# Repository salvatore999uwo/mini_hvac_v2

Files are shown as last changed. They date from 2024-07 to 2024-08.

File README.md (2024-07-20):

# mini_hvac_v2
Second version of the temperature control system for a small model room.

Photos:
As shown below, this version is made from three parts: Wooden structure, electronic boards, and thermal transfer area. 
The wooden structure is made up of a plywood base and a model room built from studs. There will be a drywall covering over the stud room to simulate a real temperature-controlled room.
The electronic boards are simply the PCB and the power supply for the project. There will be several wires running between the boards and the thermal transfer area.
The thermal transfer area is shown by the heatsinks and fans on the picture below. This area is composed of the TEC module, which creates a large temperature difference, and the heatsinks and fans that allow the TEC module to move thermal energy out of or into the room.
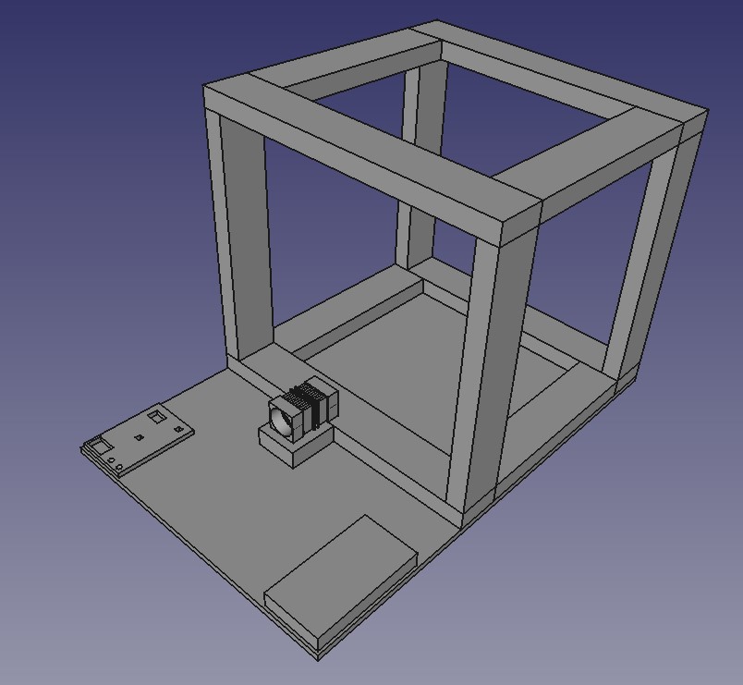
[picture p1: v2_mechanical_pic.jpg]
New Mechanical Layout


Current PCB 3D Model:
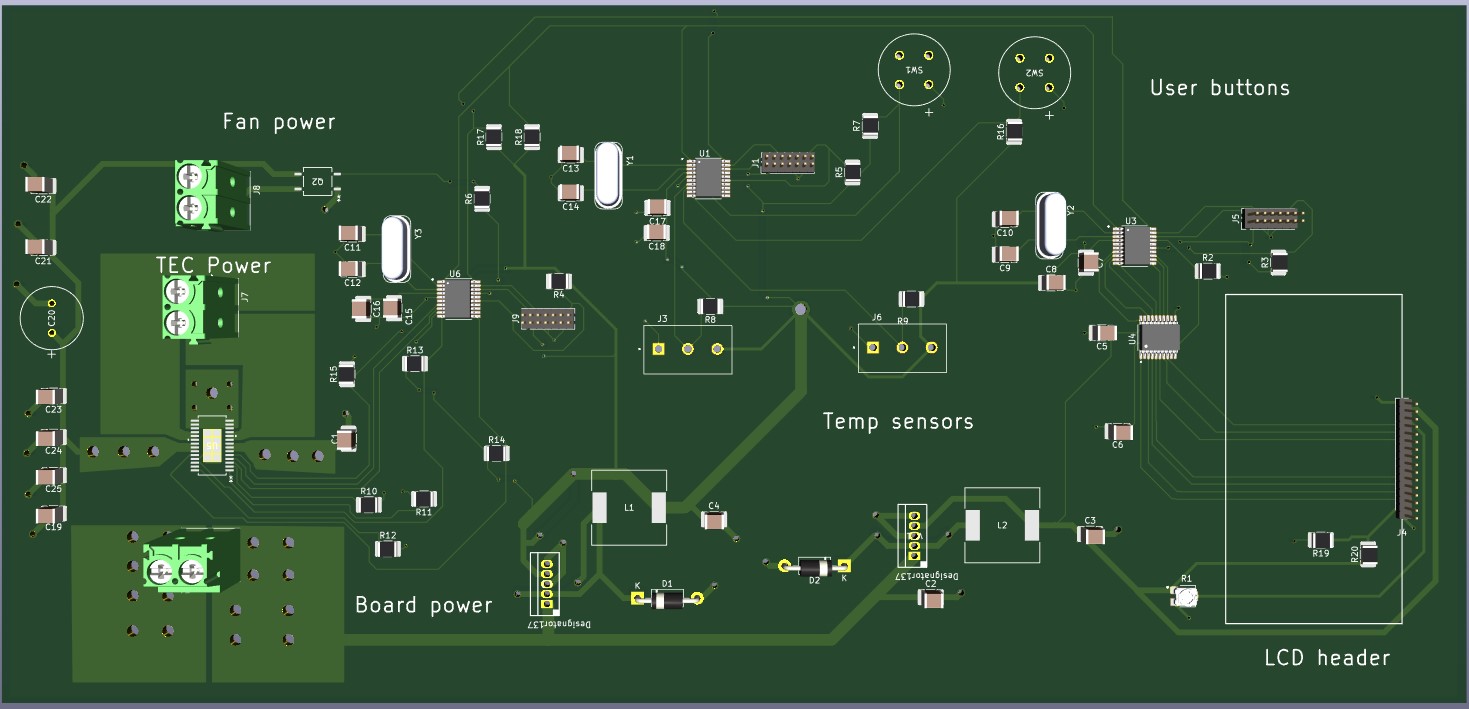
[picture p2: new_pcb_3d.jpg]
3D View


One schematic page i've been working on:
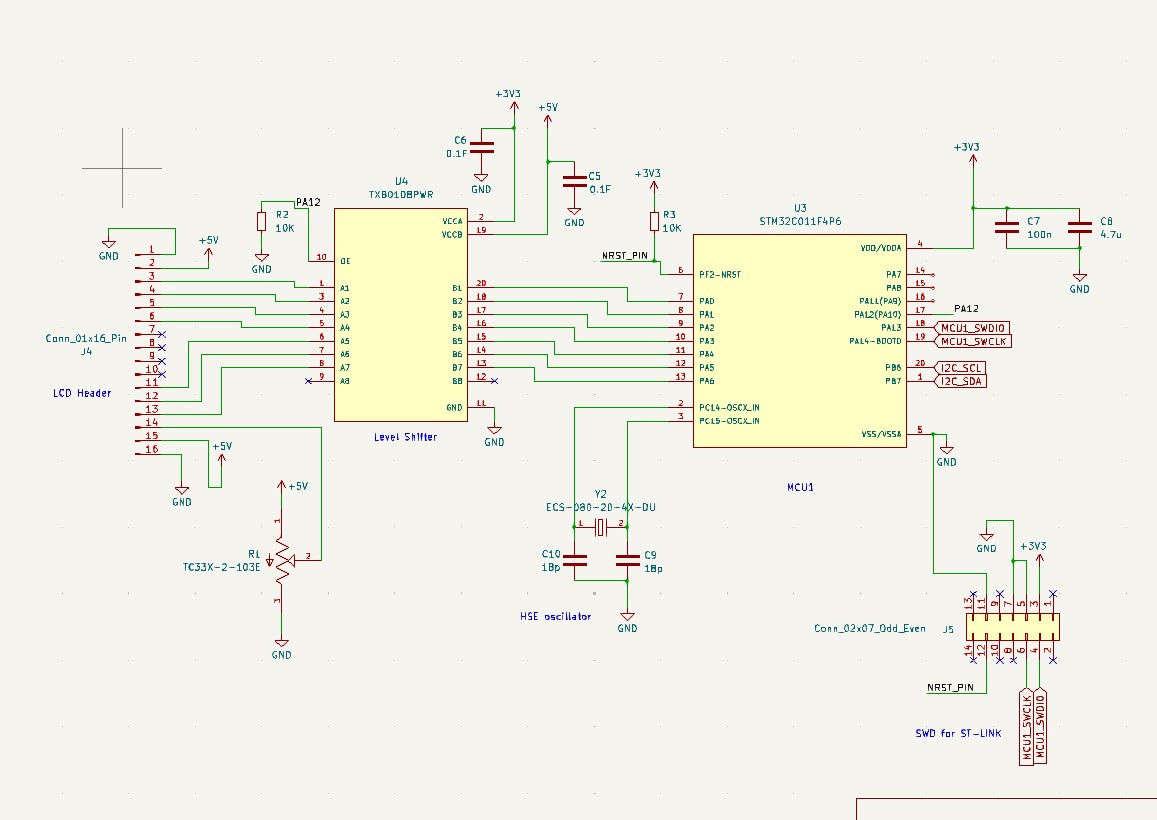
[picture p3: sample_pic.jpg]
Schematic


Current PCB Design:
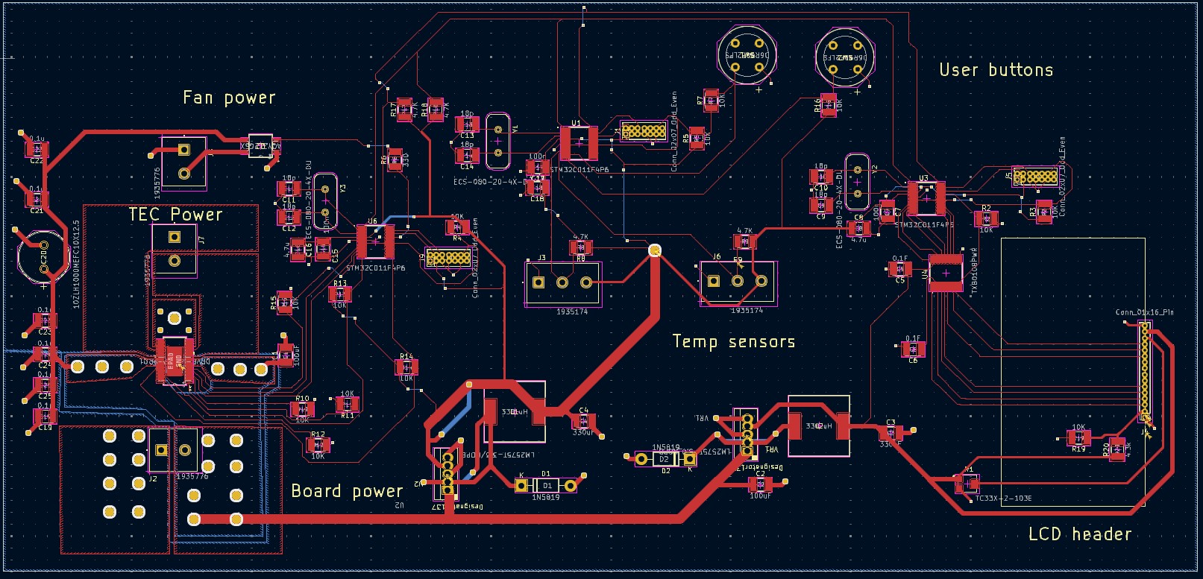
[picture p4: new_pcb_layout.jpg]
New PCB Picture


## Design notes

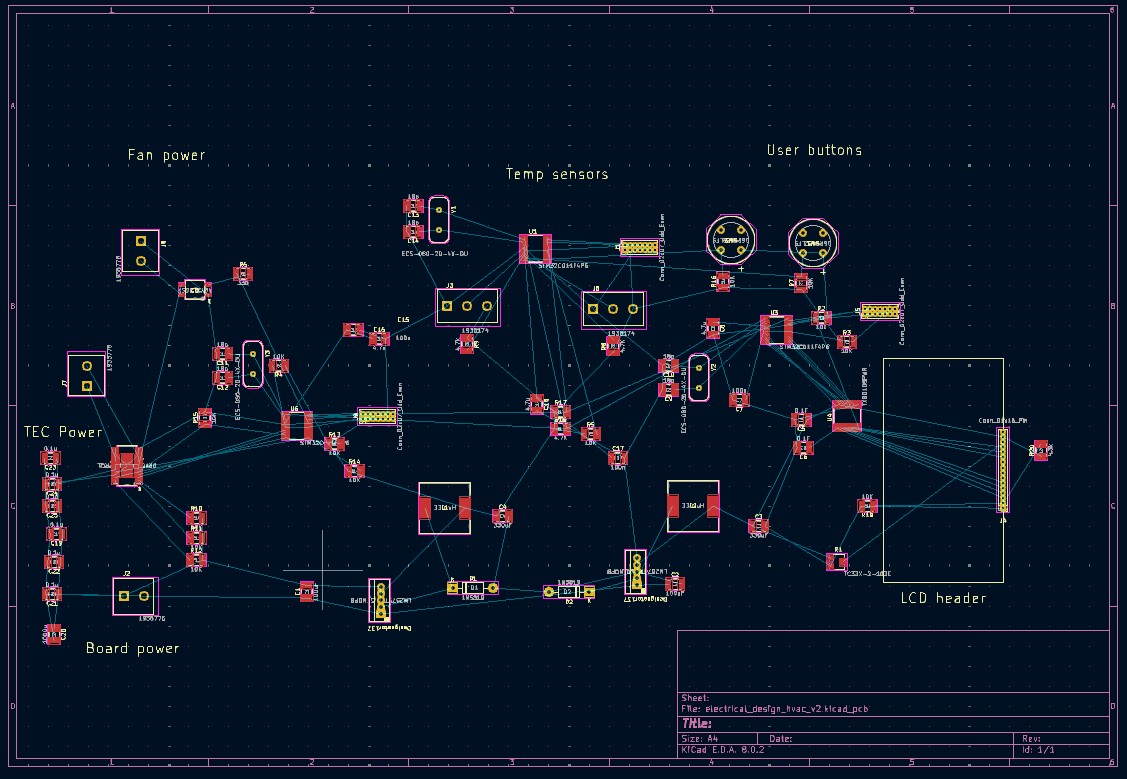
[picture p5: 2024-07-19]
pcb_one.jpg

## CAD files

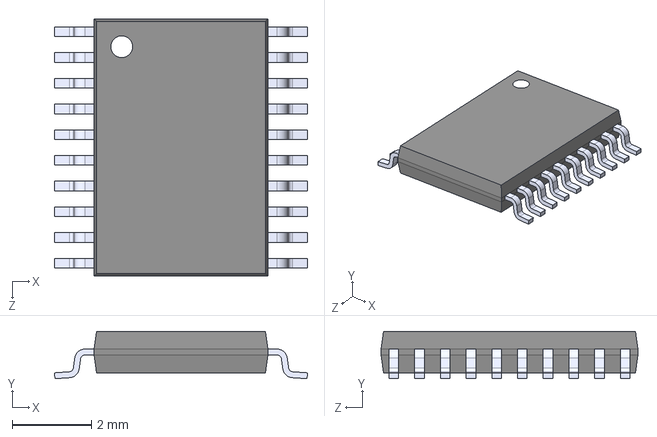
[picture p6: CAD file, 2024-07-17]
symbols_n_all/level_shifter/TXB0108PWR.step
6.40 x 1.20 x 6.50 mm

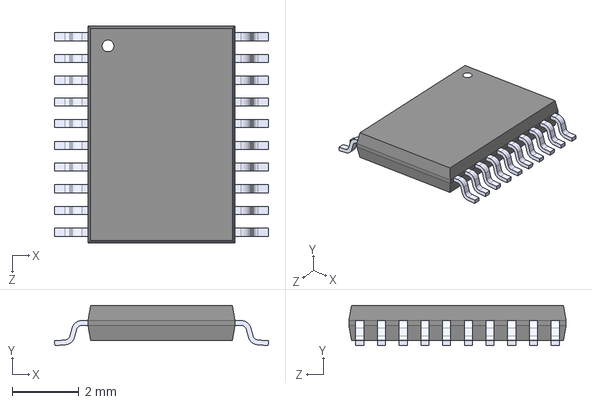
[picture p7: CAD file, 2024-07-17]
symbols_n_all/mcu/STM32C011F4P6.step
6.40 x 1.20 x 6.50 mm

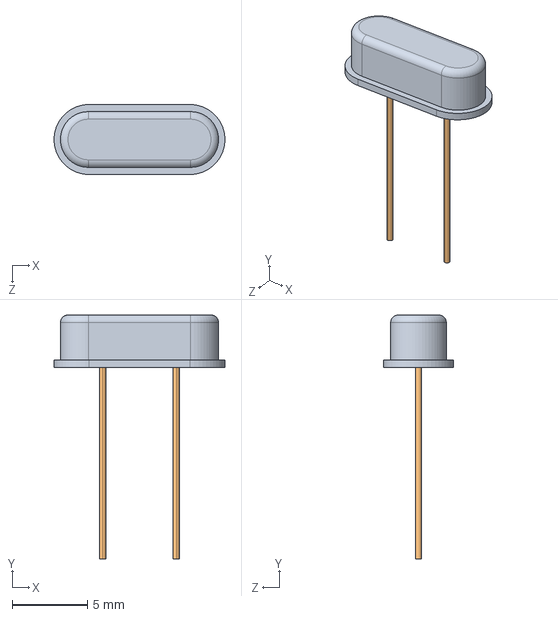
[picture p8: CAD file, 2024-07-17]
symbols_n_all/oscillator/ECS-080-20-4X-DU.step
11.4 x 16.2 x 4.65 mm

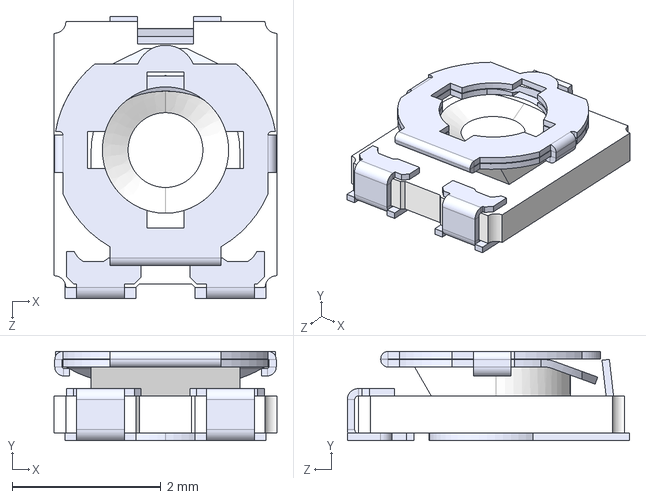
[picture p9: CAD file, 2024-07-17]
symbols_n_all/potentiometer_super/TC33X-2-103E.step
3.00 x 1.20 x 3.80 mm

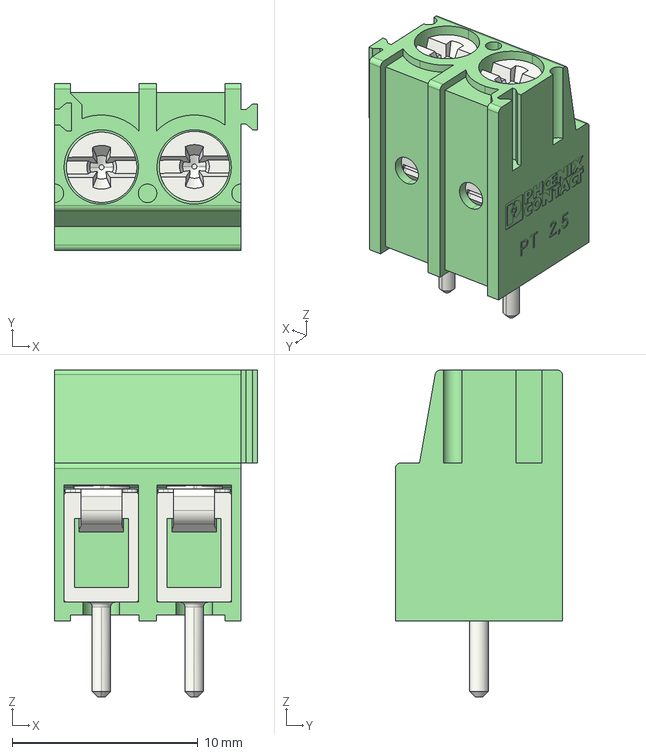
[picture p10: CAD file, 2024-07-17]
symbols_n_all/terminal_highcurrent/1935776.step
10.9 x 9.00 x 17.6 mm

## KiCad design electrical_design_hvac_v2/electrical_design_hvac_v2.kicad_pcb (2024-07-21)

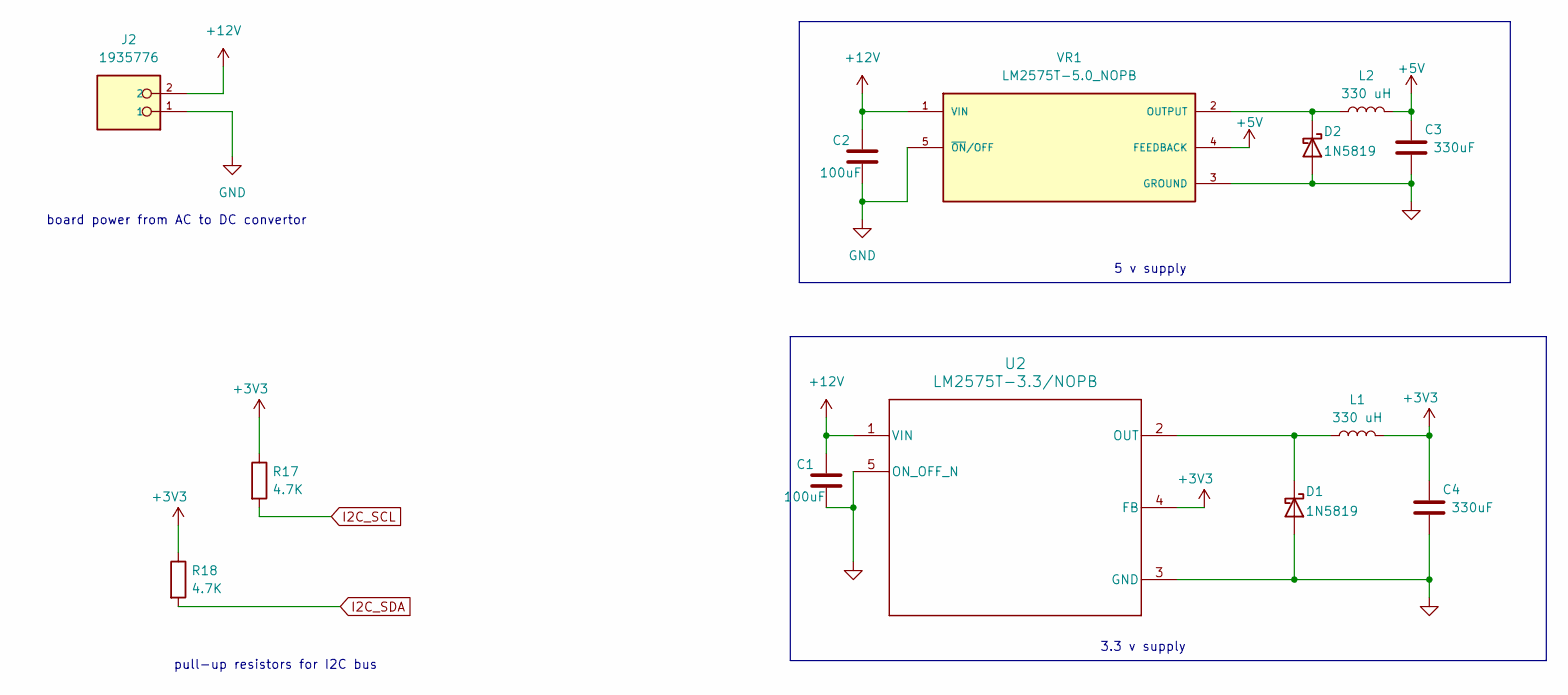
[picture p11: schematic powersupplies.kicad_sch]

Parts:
C1, C2: 100uF; C_1210_3225Metric_Pad1.33x2.70mm_HandSolder
C3, C4: 330uF; C_1210_3225Metric_Pad1.33x2.70mm_HandSolder
D1, D2: 1N5819; D_DO-41_SOD81_P10.16mm_Horizontal
J2: 1935776; PHOENIX_1935776; PARTREV 19.10.2016
L1, L2: 330 uH; IND_1210-WE-PD_WRE
R17, R18: 4.7K; R_1210_3225Metric_Pad1.30x2.65mm_HandSolder
U2: LM2575T-3.3/NOPB; KC0005A
VR1: LM2575T-5.0_NOPB; KC0005A; PARTREV E

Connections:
+5V: C3.1, L2.2, VR1.4 (FEEDBACK); also elsewhere on the board
+12V: C1.1, C2.1, J2.2, U2.1 (VIN), VR1.1 (VIN); also elsewhere on the board
GND: C1.2, C2.2, C3.2, C4.2, D1.2 (A), D2.2 (A), J2.1, U2.3 (GND), U2.5 (ON_OFF_N), VR1.3 (GROUND), VR1.5 (~ON/OFF); also elsewhere on the board
I2C_SCL: R17.2; also elsewhere on the board
I2C_SDA: R18.2; also elsewhere on the board
unnamed: D1.1 (K), L1.1, U2.2 (OUT)
unnamed: D2.1 (K), L2.1, VR1.2 (OUTPUT)

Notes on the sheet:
5 v supply
board power from AC to DC convertor
pull-up resistors for I2C bus
3.3 v supply

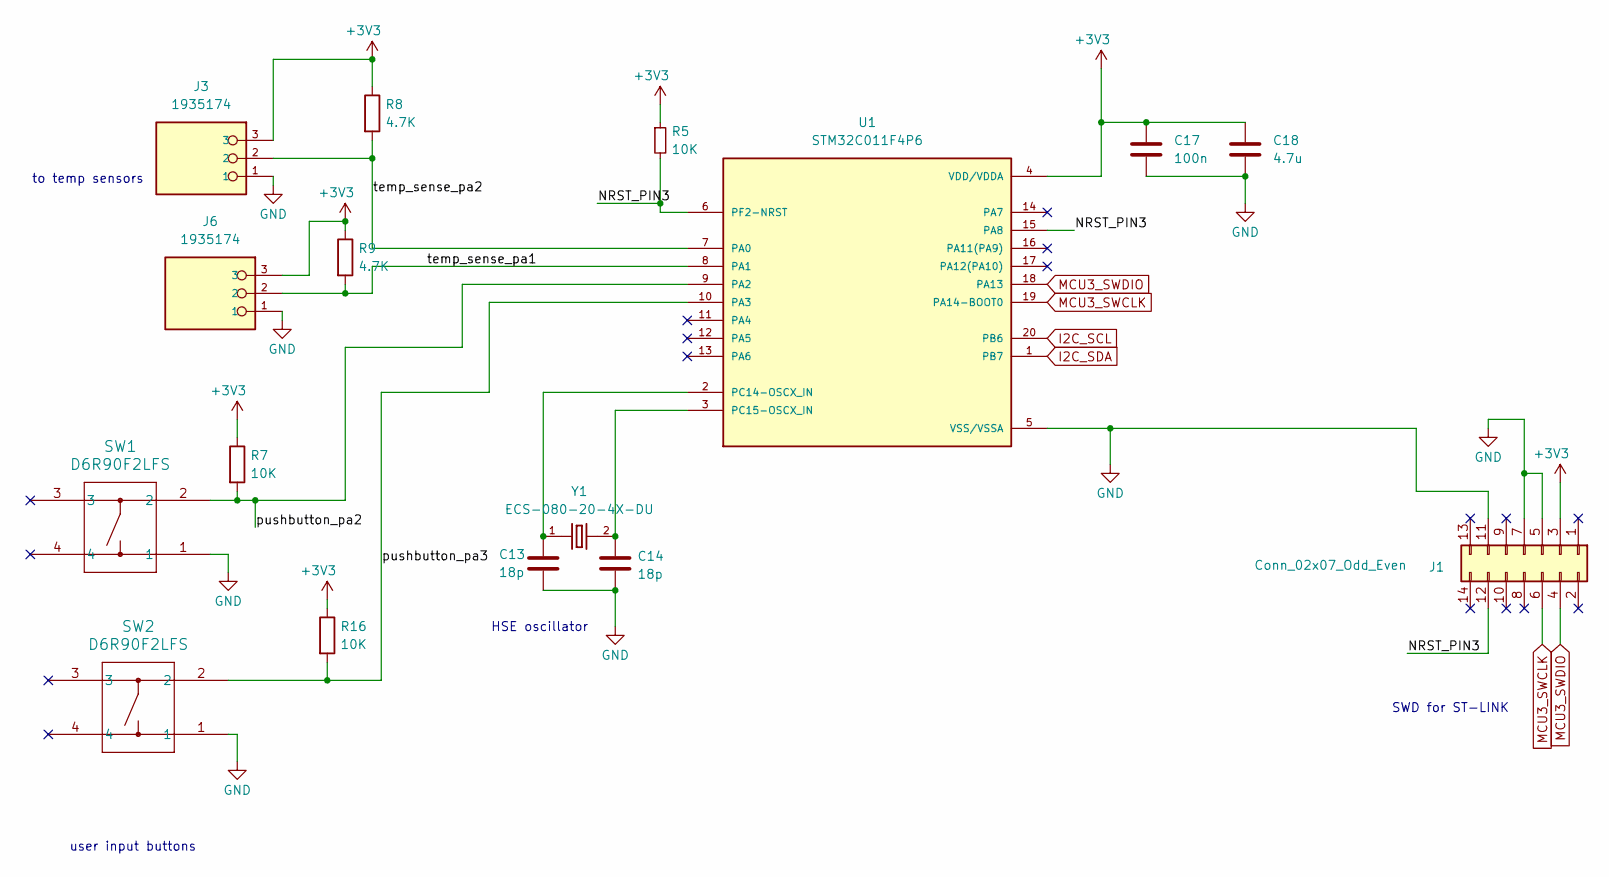
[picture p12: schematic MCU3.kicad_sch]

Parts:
C13, C14: 18p; C_1210_3225Metric_Pad1.33x2.70mm_HandSolder
C17: 100n; C_1210_3225Metric_Pad1.33x2.70mm_HandSolder
C18: 4.7u; C_1210_3225Metric_Pad1.33x2.70mm_HandSolder
J1: Conn_02x07_Odd_Even; PinHeader_2x07_P1.27mm_Vertical
J3, J6: 1935174; PHOENIX_1935174
R5, R7, R16: 10K; R_1210_3225Metric_Pad1.30x2.65mm_HandSolder
R8, R9: 4.7K; R_1210_3225Metric_Pad1.30x2.65mm_HandSolder
SW1, SW2: D6R90F2LFS; D6R90_CNK
U1: STM32C011F4P6; SOP65P640X120-20N; PARTREV 3
Y1: ECS-080-20-4X-DU; XTAL_ECS-160-20-4X

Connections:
/MCU3/NRST_PIN3: J1.12, R5.2, U1.6 (PF2-NRST), U1.15 (PA8)
/MCU3/pushbutton_pa2: R7.2, SW1.2, U1.9 (PA2)
/MCU3/pushbutton_pa3: R16.2, SW2.2, U1.10 (PA3)
/MCU3/temp_sense_pa1: J6.2, R9.2, U1.8 (PA1)
/MCU3/temp_sense_pa2: J3.2, R8.2, U1.7 (PA0)
GND: C13.2, C14.2, C17.2, C18.2, J1.5, J1.7, J1.11, J3.1, J6.1, SW1.1, SW2.1, U1.5 (VSS/VSSA); also elsewhere on the board
I2C_SCL: U1.20 (PB6); also elsewhere on the board
I2C_SDA: U1.1 (PB7); also elsewhere on the board
MCU3_SWCLK: J1.6, U1.19 (PA14-BOOT0)
MCU3_SWDIO: J1.4, U1.18 (PA13)
unnamed: C13.1, U1.2 (PC14-OSCX_IN), Y1.1
unnamed: C14.1, U1.3 (PC15-OSCX_IN), Y1.2

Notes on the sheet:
HSE oscillator
user input buttons
SWD for ST-LINK
to temp sensors

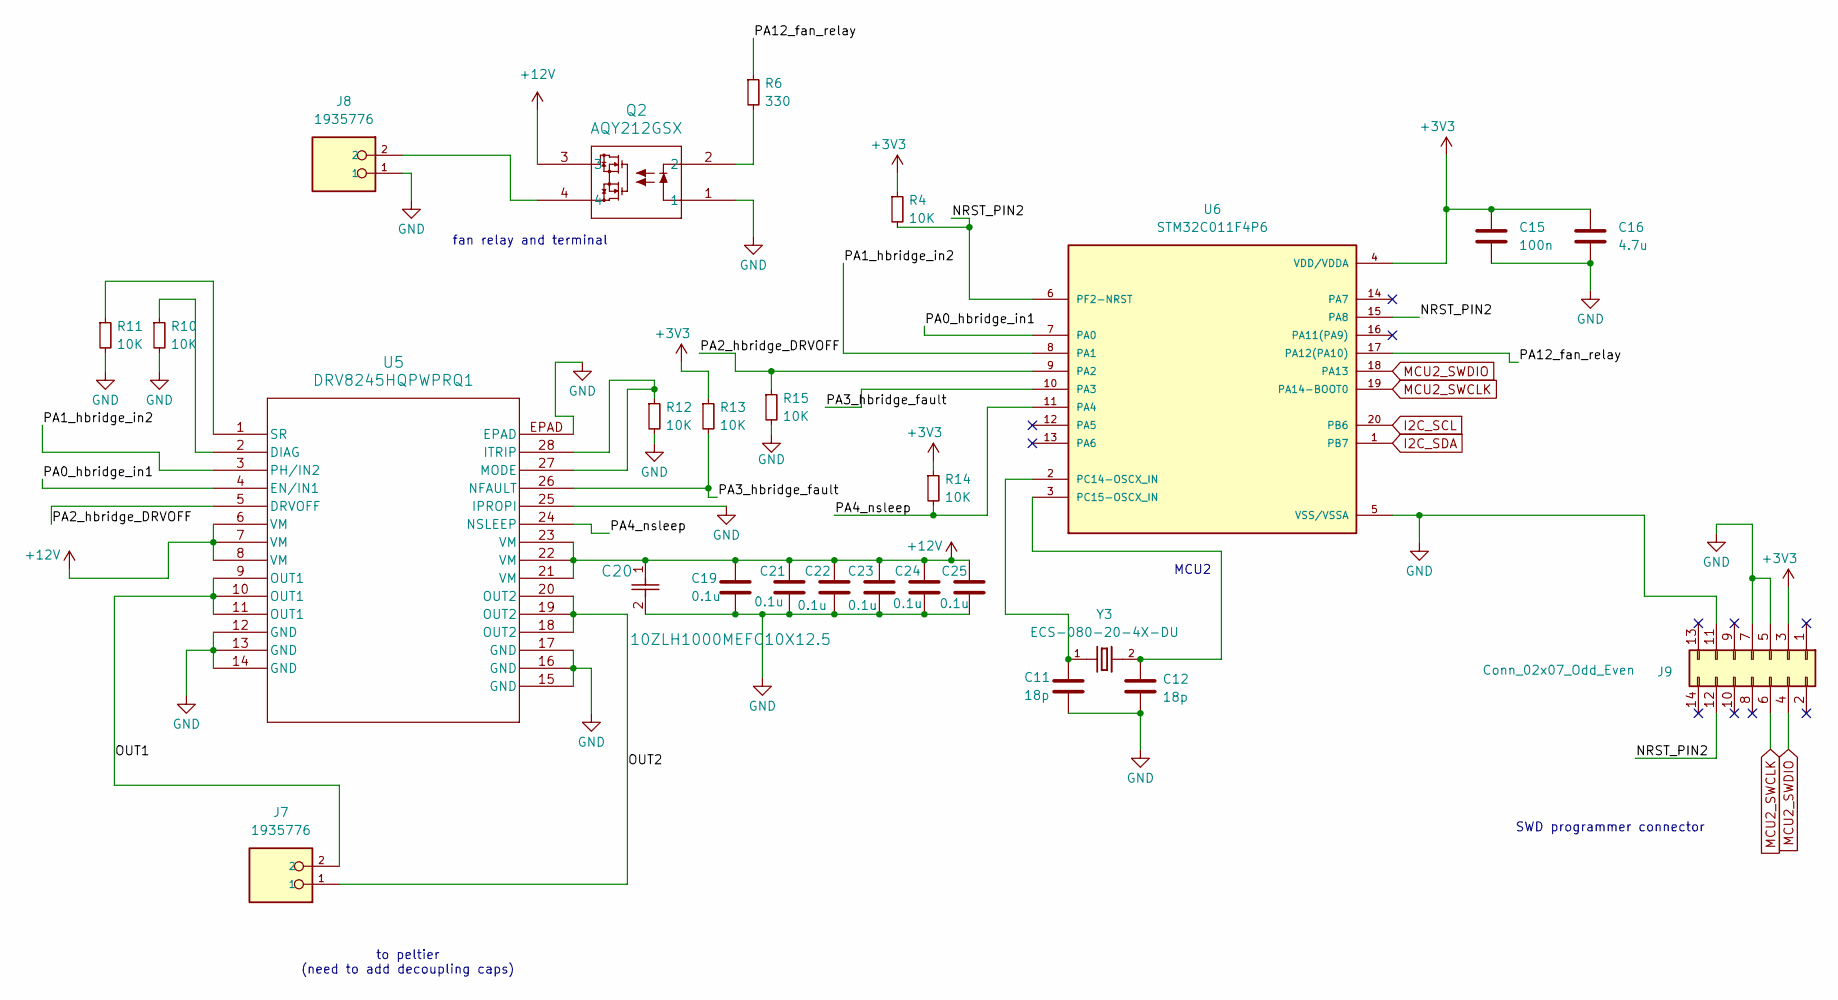
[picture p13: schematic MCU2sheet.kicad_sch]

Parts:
C11, C12: 18p; C_1210_3225Metric_Pad1.33x2.70mm_HandSolder
C15: 100n; C_1210_3225Metric_Pad1.33x2.70mm_HandSolder
C16: 4.7u; C_1210_3225Metric_Pad1.33x2.70mm_HandSolder
C19, C21, C22, C23, C24, C25: 0.1u; C_1210_3225Metric_Pad1.33x2.70mm_HandSolder
C20: 10ZLH1000MEFC10X12.5; CAP_10X12.5_RUB
J7, J8: 1935776; PHOENIX_1935776; PARTREV 19.10.2016
J9: Conn_02x07_Odd_Even; PinHeader_2x07_P1.27mm_Vertical
Q2: AQY212GSX; SOP4_PAN
R4, R10, R11, R12, R13, R14, R15: 10K; R_1210_3225Metric_Pad1.30x2.65mm_HandSolder
R6: 330; R_1210_3225Metric_Pad1.30x2.65mm_HandSolder
U5: DRV8245HQPWPRQ1; HTSSOP28_PWP_TEX
U6: STM32C011F4P6; SOP65P640X120-20N; PARTREV 3
Y3: ECS-080-20-4X-DU; XTAL_ECS-160-20-4X

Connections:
+12V: C19.1, C20.1, C21.1, C22.1, C23.1, C24.1, C25.1, Q2.3, U5.6 (VM), U5.7 (VM), U5.8 (VM), U5.21 (VM), U5.22 (VM), U5.23 (VM); also elsewhere on the board
/MCU2/NRST_PIN2: J9.12, R4.2, U6.6 (PF2-NRST), U6.15 (PA8)
/MCU2/OUT1: J7.2, U5.9 (OUT1), U5.10 (OUT1), U5.11 (OUT1)
/MCU2/OUT2: J7.1, U5.18 (OUT2), U5.19 (OUT2), U5.20 (OUT2)
/MCU2/PA0_hbridge_in1: U5.4 (EN/IN1), U6.7 (PA0)
/MCU2/PA1_hbridge_in2: U5.3 (PH/IN2), U6.8 (PA1)
/MCU2/PA2_hbridge_DRVOFF: R15.1, U5.5 (DRVOFF), U6.9 (PA2)
/MCU2/PA3_hbridge_fault: R13.2, U5.26 (NFAULT), U6.10 (PA3)
/MCU2/PA4_nsleep: R14.2, U5.24 (NSLEEP), U6.11 (PA4)
/MCU2/PA12_fan_relay: R6.1, U6.17 (PA12(PA10))
GND: C11.2, C12.2, C15.2, C16.2, C19.2, C20.2, C21.2, C22.2, C23.2, C24.2, C25.2, J8.1, J9.5, J9.7, J9.11, Q2.1, R10.2, R11.2, R12.2, R15.2, U5.12 (GND), U5.13 (GND), U5.14 (GND), U5.15 (GND), U5.16 (GND), U5.17 (GND), U5.25 (IPROPI), U5.EPAD, U6.5 (VSS/VSSA); also elsewhere on the board
I2C_SCL: U6.20 (PB6); also elsewhere on the board
I2C_SDA: U6.1 (PB7); also elsewhere on the board
MCU2_SWCLK: J9.6, U6.19 (PA14-BOOT0)
MCU2_SWDIO: J9.4, U6.18 (PA13)
unnamed: J8.2, Q2.4
unnamed: Q2.2, R6.2
unnamed: R10.1, U5.2 (DIAG)
unnamed: R12.1, U5.27 (MODE), U5.28 (ITRIP)
unnamed: R11.1, U5.1 (SR)
unnamed: C11.1, U6.2 (PC14-OSCX_IN), Y3.1
unnamed: C12.1, U6.3 (PC15-OSCX_IN), Y3.2

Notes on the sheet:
to peltier (need to add decoupling caps)
fan relay and terminal
MCU2
SWD programmer connector

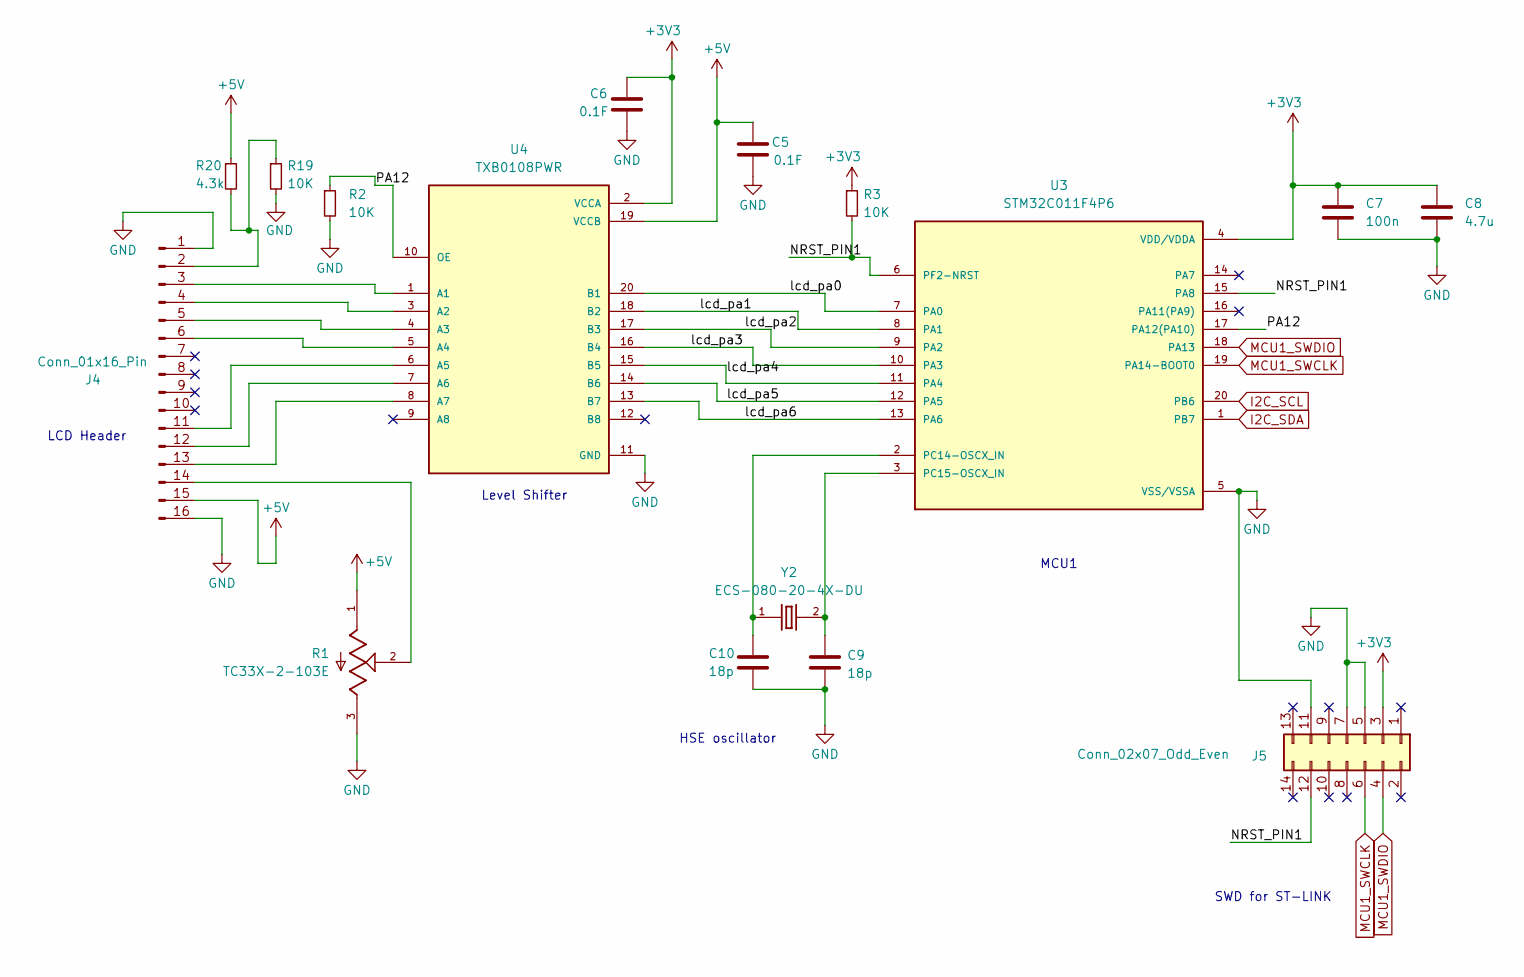
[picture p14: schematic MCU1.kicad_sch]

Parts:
C5, C6: 0.1F; C_1210_3225Metric_Pad1.33x2.70mm_HandSolder
C7: 100n; C_1210_3225Metric_Pad1.33x2.70mm_HandSolder
C8: 4.7u; C_1210_3225Metric_Pad1.33x2.70mm_HandSolder
C9, C10: 18p; C_1210_3225Metric_Pad1.33x2.70mm_HandSolder
J4: Conn_01x16_Pin; PinHeader_1x16_P1.27mm_Vertical
J5: Conn_02x07_Odd_Even; PinHeader_2x07_P1.27mm_Vertical
R1: TC33X-2-103E; TRIM_TC33X-2-103E
R2, R3, R19: 10K; R_1210_3225Metric_Pad1.30x2.65mm_HandSolder
R20: 4.3k; R_1210_3225Metric_Pad1.30x2.65mm_HandSolder
U3: STM32C011F4P6; SOP65P640X120-20N; PARTREV 3
U4: TXB0108PWR; SOP65P640X120-20N; PARTREV H
Y2: ECS-080-20-4X-DU; XTAL_ECS-160-20-4X

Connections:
+5V: C5.1, J4.15, R1.1, R20.1, U4.19 (VCCB); also elsewhere on the board
/MCU1/NRST_PIN1: J5.12, R3.2, U3.6 (PF2-NRST), U3.15 (PA8)
/MCU1/PA12: R2.1, U3.17 (PA12(PA10)), U4.10 (OE)
/MCU1/lcd_pa0: U3.7 (PA0), U4.20 (B1)
/MCU1/lcd_pa1: U3.8 (PA1), U4.18 (B2)
/MCU1/lcd_pa2: U3.9 (PA2), U4.17 (B3)
/MCU1/lcd_pa3: U3.10 (PA3), U4.16 (B4)
/MCU1/lcd_pa4: U3.11 (PA4), U4.15 (B5)
/MCU1/lcd_pa5: U3.12 (PA5), U4.14 (B6)
/MCU1/lcd_pa6: U3.13 (PA6), U4.13 (B7)
GND: C5.2, C6.2, C7.2, C8.2, C9.2, C10.2, J4.1, J4.16, J5.5, J5.7, J5.11, R1.3, R2.2, R19.2, U3.5 (VSS/VSSA), U4.11 (GND); also elsewhere on the board
I2C_SCL: U3.20 (PB6); also elsewhere on the board
I2C_SDA: U3.1 (PB7); also elsewhere on the board
MCU1_SWCLK: J5.6, U3.19 (PA14-BOOT0)
MCU1_SWDIO: J5.4, U3.18 (PA13)
unnamed: J4.2, R19.1, R20.2
unnamed: J4.3, U4.1 (A1)
unnamed: J4.4, U4.3 (A2)
unnamed: J4.5, U4.4 (A3)
unnamed: J4.6, U4.5 (A4)
unnamed: J4.11, U4.6 (A5)
unnamed: J4.12, U4.7 (A6)
unnamed: J4.13, U4.8 (A7)
unnamed: J4.14, R1.2
unnamed: C10.1, U3.2 (PC14-OSCX_IN), Y2.1
unnamed: C9.1, U3.3 (PC15-OSCX_IN), Y2.2

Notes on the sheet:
Level Shifter
MCU1
LCD Header
HSE oscillator
SWD for ST-LINK

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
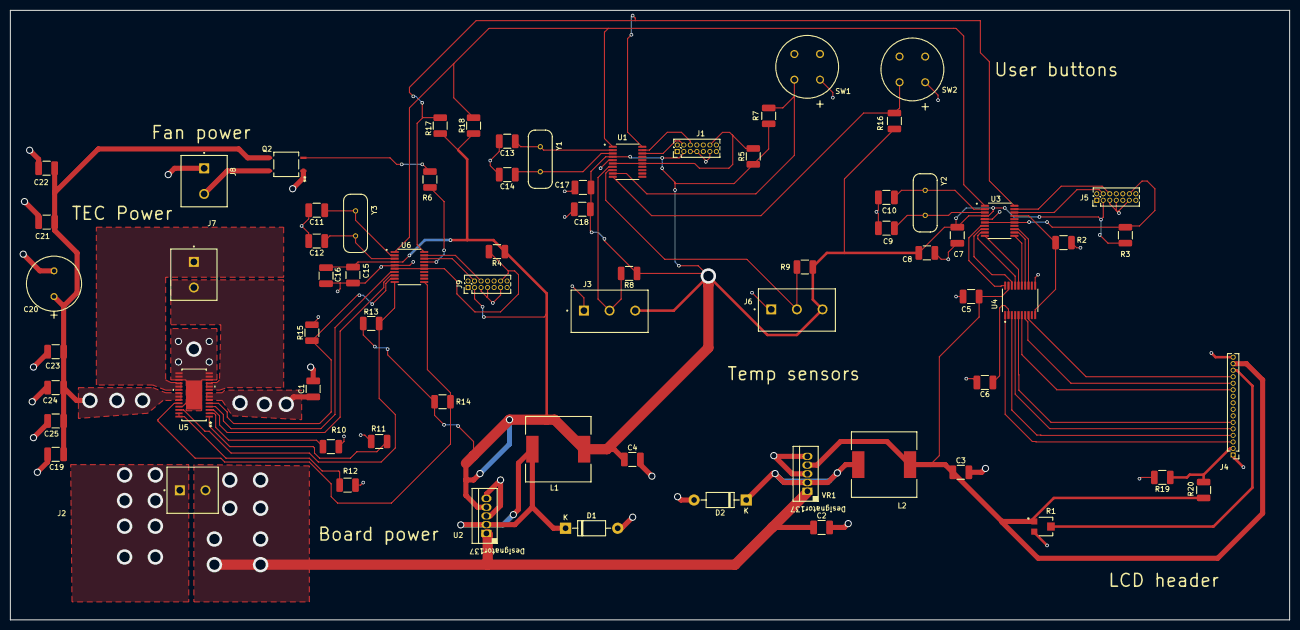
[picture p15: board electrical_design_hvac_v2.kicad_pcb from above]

Board: 2 copper layers, 249.2 x 118.8 mm, 71 parts (0 on the bottom side), 58 nets.

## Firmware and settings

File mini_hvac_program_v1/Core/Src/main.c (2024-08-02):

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
/* Includes ------------------------------------------------------------------*/
#include "main.h"

TIM_HandleTypeDef htim1;

void SystemClock_Config(void);
static void MX_GPIO_Init(void);
static void MX_TIM1_Init(void);
/* USER CODE BEGIN PFP */

void One_Wire_Init(void);
void DS18B20_Read_Temperature(int* temp);
void hbridge_colder(void);
void hbridge_hotter(void);
void display_on_LCD(int desired, int real);
/* USER CODE END PFP */

/**
  * @brief  The application entry point.
  * @retval int
  */
int main(void)
{

  /* USER CODE BEGIN 1 */
	int desired_temp = 20;
	int real_temp = 0;
  /* USER CODE END 1 */

  /* MCU Configuration--------------------------------------------------------*/

  /* Reset of all peripherals, Initializes the Flash interface and the Systick. */
  HAL_Init();

  /* Configure the system clock */
  SystemClock_Config();

  /* Initialize all configured peripherals */
  MX_GPIO_Init();
  MX_TIM1_Init();
  /* USER CODE BEGIN 2 */

  One_Wire_Init();
  /* USER CODE END 2 */

  /* Infinite loop */
  /* USER CODE BEGIN WHILE */
  while (1)
  {
      DS18B20_Read_Temperature(&real_temp);

      if (HAL_GPIO_ReadPin(BUTTON_GPIO_PORT, BUTTON1_PIN) == GPIO_PIN_RESET) {
          desired_temp++;
          HAL_Delay(200); // Debounce delay
      }

      if (abs(real_temp - desired_temp) > 3) {
          HAL_GPIO_WritePin(FAN_RELAY_GPIO_PORT, FAN_RELAY_PIN, GPIO_PIN_SET);
          if (real_temp > desired_temp) {
              hbridge_colder();
          } else {
              hbridge_hotter();
          }
      } else {
          HAL_GPIO_WritePin(FAN_RELAY_GPIO_PORT, FAN_RELAY_PIN, GPIO_PIN_RESET);
      }

      display_on_LCD(desired_temp, real_temp);
      HAL_Delay(1000); // Delay to prevent rapid signal sending
  }

    /* USER CODE END WHILE */

    /* USER CODE BEGIN 3 */
  }
  /* USER CODE END 3 */
}

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
/* USER CODE BEGIN 4 */
void DS18B20_Read_Temperature(int* temp) {
    // Read temperature from DS18B20 sensor and store in temp
    // This function needs to be implemented according to the DS18B20 protocol
}

void display_on_LCD(int desired, int real) {
    // Display desired_temp and real_temp on the LCD
    // This function needs to be implemented according to your LCD setup
}

/* USER CODE END 4 */
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


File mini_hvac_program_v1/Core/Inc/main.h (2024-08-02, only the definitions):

#define LCD1_Pin GPIO_PIN_0
#define LCD1_GPIO_Port GPIOB
#define LCD2_Pin GPIO_PIN_1
#define LCD2_GPIO_Port GPIOB
#define LCD3_Pin GPIO_PIN_2
#define LCD3_GPIO_Port GPIOB
#define LCD10_Pin GPIO_PIN_10
#define LCD10_GPIO_Port GPIOB
#define HBRIDGE_SLEEP1_Pin GPIO_PIN_11
#define HBRIDGE_SLEEP1_GPIO_Port GPIOB
#define HBRIDGE_SLEEP2_Pin GPIO_PIN_12
#define HBRIDGE_SLEEP2_GPIO_Port GPIOB
#define LCD11_Pin GPIO_PIN_13
#define LCD11_GPIO_Port GPIOB
#define FAN_RELAY_Pin GPIO_PIN_10
#define FAN_RELAY_GPIO_Port GPIOA
#define TEMP_SENSOR1_Pin GPIO_PIN_11
#define TEMP_SENSOR1_GPIO_Port GPIOA
#define TEMP_SENSOR2_Pin GPIO_PIN_12
#define TEMP_SENSOR2_GPIO_Port GPIOA
#define LCD4_Pin GPIO_PIN_3
#define LCD4_GPIO_Port GPIOB
#define LCD5_Pin GPIO_PIN_4
#define LCD5_GPIO_Port GPIOB
#define LCD6_Pin GPIO_PIN_5
#define LCD6_GPIO_Port GPIOB
#define LCD7_Pin GPIO_PIN_6
#define LCD7_GPIO_Port GPIOB
#define LCD8_Pin GPIO_PIN_7
#define LCD8_GPIO_Port GPIOB
#define PCB9_Pin GPIO_PIN_9
#define PCB9_GPIO_Port GPIOB

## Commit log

2024-07-17 new electrical schematics
    [MCU1.kicad_sch, MCU2sheet.kicad_sch, MCU3.kicad_sch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]
2024-07-17 Add files via upload
    keeping these symbol files for the electrical design
    [1935776.step, ECS-080-20-4X-DU.step, STM32C011F4P6.step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]
2024-07-19 Add files via upload
    new photo of pcb

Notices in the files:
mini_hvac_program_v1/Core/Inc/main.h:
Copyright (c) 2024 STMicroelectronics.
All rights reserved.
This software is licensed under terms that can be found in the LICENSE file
